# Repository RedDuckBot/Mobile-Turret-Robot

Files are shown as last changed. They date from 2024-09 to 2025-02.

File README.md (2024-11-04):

# Mobile Turret Robot
A differential drive robot, named Stroam, is equipped with a one degree of freedom turret that shoots foam balls. 
Currently, Stroam is only controlled manually where an Xbox 360 controller is used to drive and operate the turret.
Most of Stroam's software was built on the framework ROS2 Humble. Here's the link for a full video of manually operating Stroam: https://www.youtube.com/watch?v=MlZp5pD2vLs

<p align='center'>
    
</p>
<p align='center'>
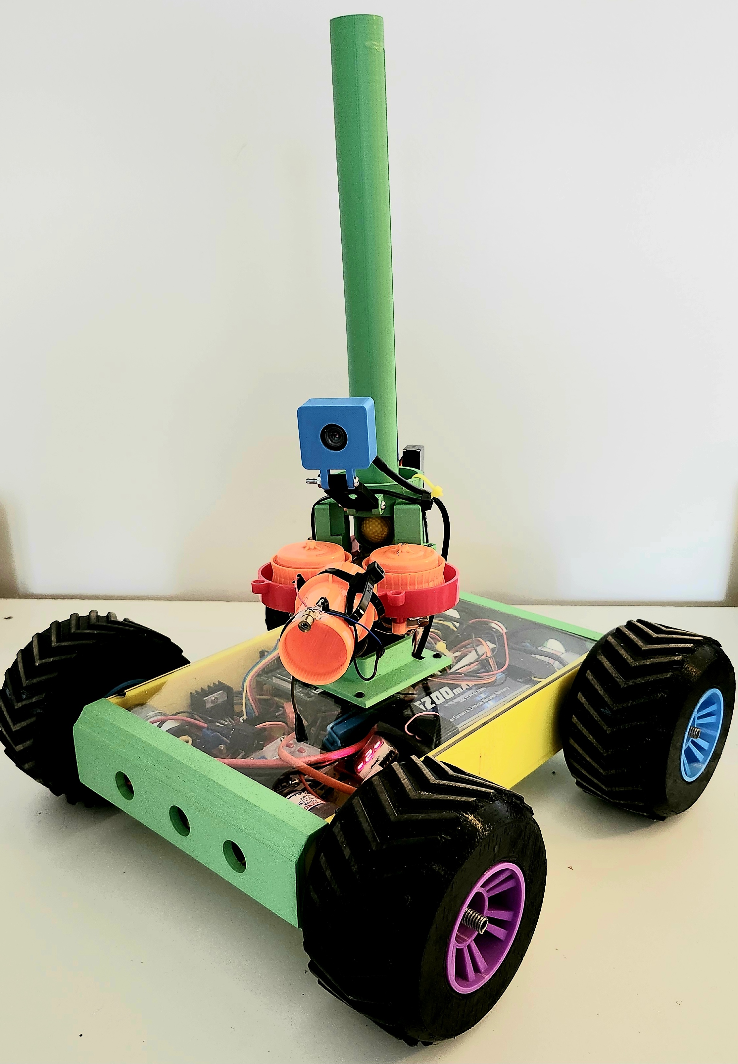
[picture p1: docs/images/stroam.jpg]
    
</p>

## 🗃️ Package Overview
- [`stroam_bringup`](./bot_setup/startup/ros2_ws/src/stroam_bringup/) : Launches camera, robot manager, motor controller, and turret nodes.
- [`stroam_camera`](./bot_setup/startup/ros2_ws/src/stroam_camera/) : Lifecycle node that provides a turret view
- [`stroam_interfaces`](./bot_setup/startup/ros2_ws/src/stroam_interfaces) : Contains action definitions for motor controller and turret operations, as well as 
a message representing Xbox 360 controller inputs.
- [`stroam_manager`](./bot_setup/startup/ros2_ws/src/stroam_manager/) : The main node running on Stroam that routes and translates controller inputs into actions that are used by the motor controller and turret nodes.
- [`stroam_motor_controller`](./bot_setup/startup/ros2_ws/src/stroam_motor_controller/) : Contains an action server for operating Stroam's motors.
- [`stroam_turret`](./bot_setup/startup/ros2_ws/src/stroam_turret/) : Contains an action server for operating Stroam's one degree of freedom turret.
- [`remote_controller`](./remote_setup/ros2_ws/src/remote_controller/) : Contains a publishing node for Xbox 360 controller from a remote computer. 
## 🧰 Hardware

<table>
  <tr>
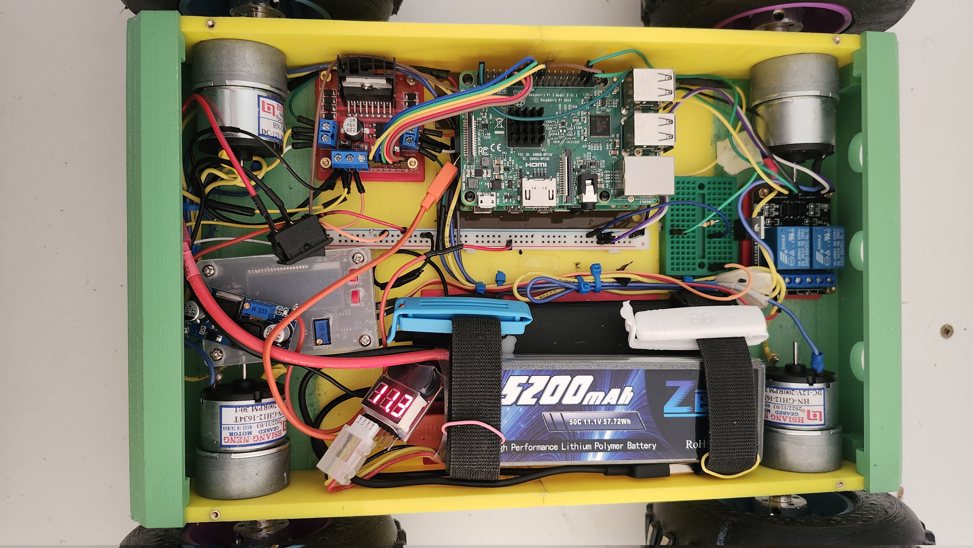
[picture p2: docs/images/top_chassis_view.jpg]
    <td></td>
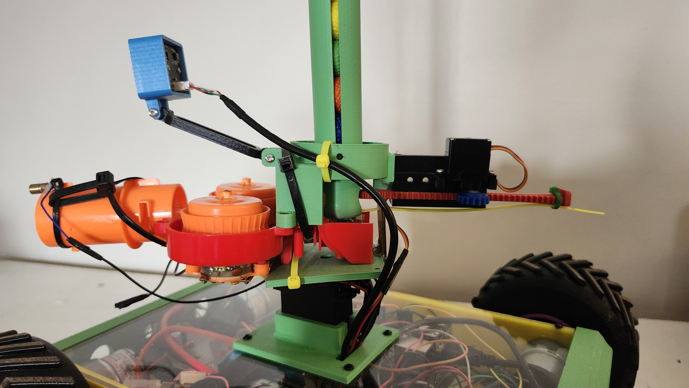
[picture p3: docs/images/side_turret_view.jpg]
    <td></td>
  </tr>
  <tr>
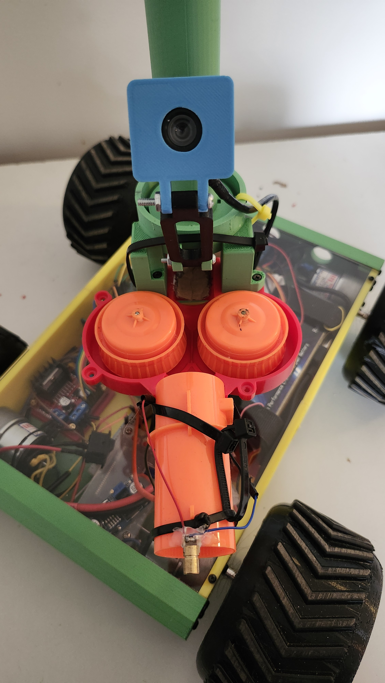
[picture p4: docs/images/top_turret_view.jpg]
    <td></td>
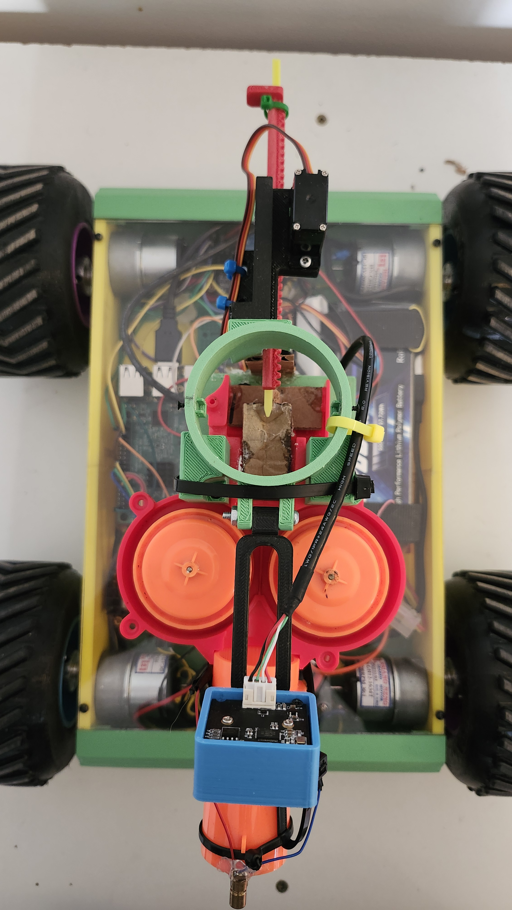
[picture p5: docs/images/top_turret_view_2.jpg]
    <td></td>
  </tr>
</table>

| | Components |
| --| --|
|1| Raspberry PI 3B+ | 
|2| 2 Channel Relay Module | 
|3| Motor Controller L298N |
|4| 2 X DC-DC Step Down Converter |
|5| [4 X DC-12V-200RPM Motors](https://ca.robotshop.com/products/lynxmotion-12vdc-200rpm-078kg-cm-ghm-16-w-rear-shaft?variant=42411388829847) | 
|7| NPN MOSFET |
|8| 460Ω Resistor |
|9| 5V Laser Diode |
|10| USB Camera |
|11| Servo MG996R |
|12| Servo (micro) MG90 |
|13| 12V, 5200mAh LIPO Battery |
|14| 5V, 10000mAh Battery Bank |

### 3D Printed Parts

The only stl files provided in this project are the ones used to build the chassis, given that the turret was a hacked design: turret is composed of 3D printed parts that are fitted to a shooting mechanism taken out a NERF Rival gun. The tires and rims are connected to motors shafts using [6mm universal hubs](https://ca.robotshop.com/products/lynxmotion-hub-02-universal-hub?variant=42413375488151) and 3D printed axel. However, the 3D printed axel was not used in this robot since they kept breaking due to radial load; instead some big bolts were machine down on a metal lath and fitted into the tires. And for the top chassis cover, a clear acyrlic sheet was cut out and fitted using a CNC machine (the stl file for this is found in the 3D_prints directory).

##  ⚡ Circuit Diagrams
The Raspberry PI 3B+ was powered using a 5V power bank while all other devices in the project were powered from the 12V LIPO battery.

### Turret Schematic 
<p align="center">
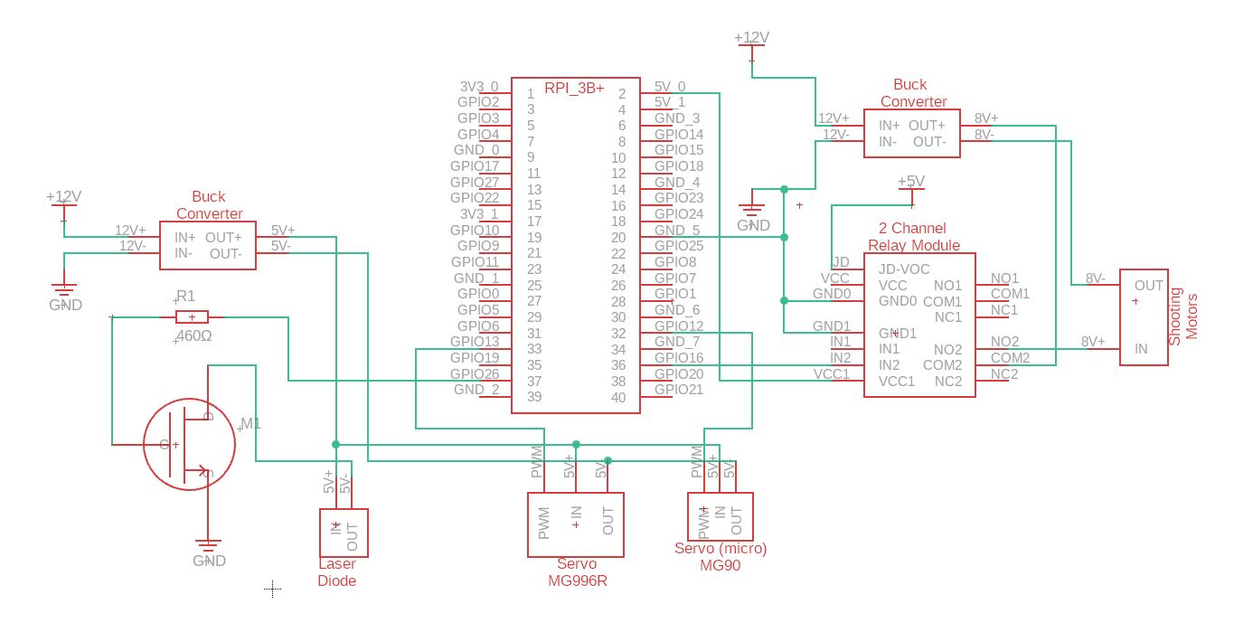
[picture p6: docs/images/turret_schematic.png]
Turret Circuit
  
</p>
Two step down converts were used to power devices for the turret system: 12V to 5V for devices like servos, laser diode and 2 channel relay module, and 12V to 8V for powering the shooting motors. As shown in the turret schematic, a NPN mosfet was used to turn on and off the laser diode by connecting a GPIO pin from the Raspberry PI to it's gate. 

### Drive System Schematic
<p align="center">
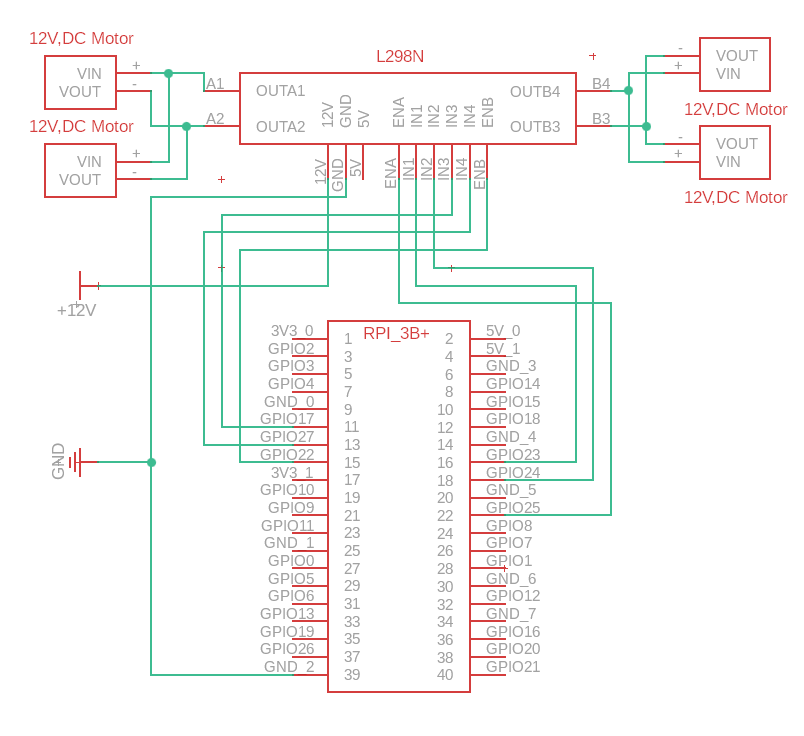
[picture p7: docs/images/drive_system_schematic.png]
Drive system Circuit
  
</p>

As shown in the above schematic, a L298N motor controller is connected to a Rasberry PI 3B+ for operating the 4 DC motors.

## 🔮 Future Work
Currently, Stroam can only be operated manually; however, the plan is to provide the robot with the task of following a route with targets off to the side.
This task is meant to be performed autonmously and will be a computer vision application. Also, there are plans for adding another degree of rotational movement since Stroam only has yaw and no pitch.

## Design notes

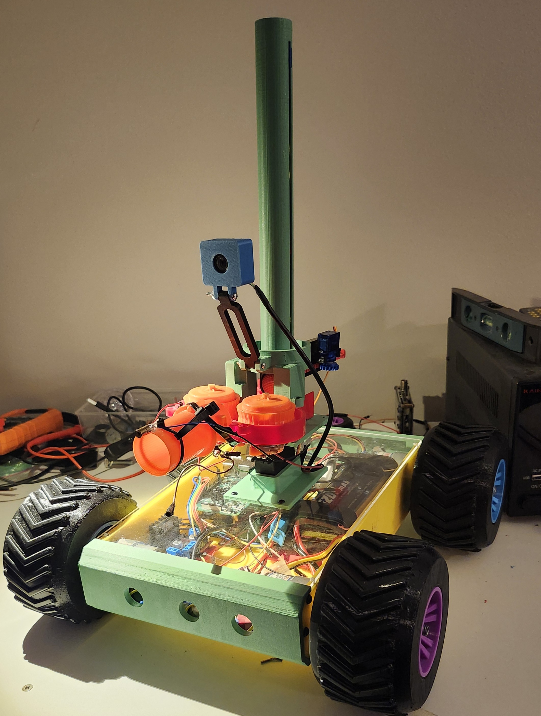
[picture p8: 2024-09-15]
docs/images/bot_pic.jpg

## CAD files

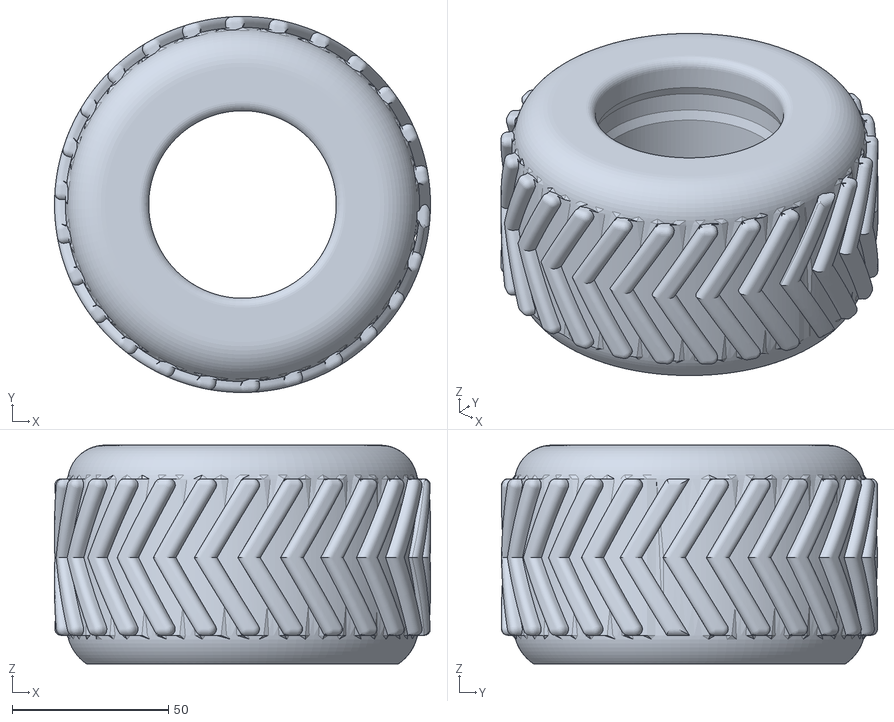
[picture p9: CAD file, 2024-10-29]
3d_prints/tire.stl
120.3 x 120.3 x 70.0

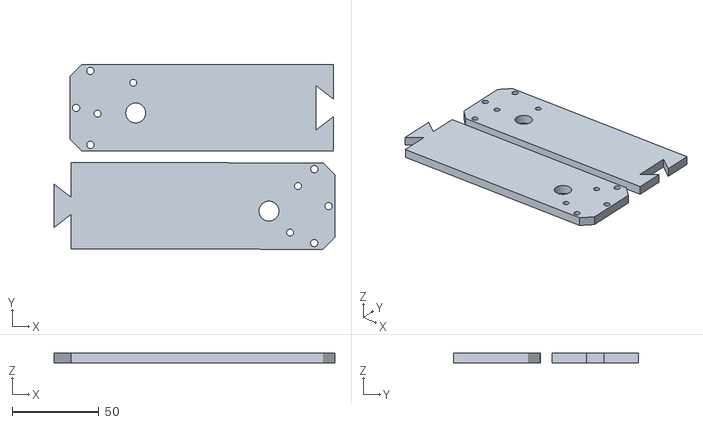
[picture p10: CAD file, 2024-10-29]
3d_prints/chassis_side_cover.stl
161.9 x 106.4 x 5.84

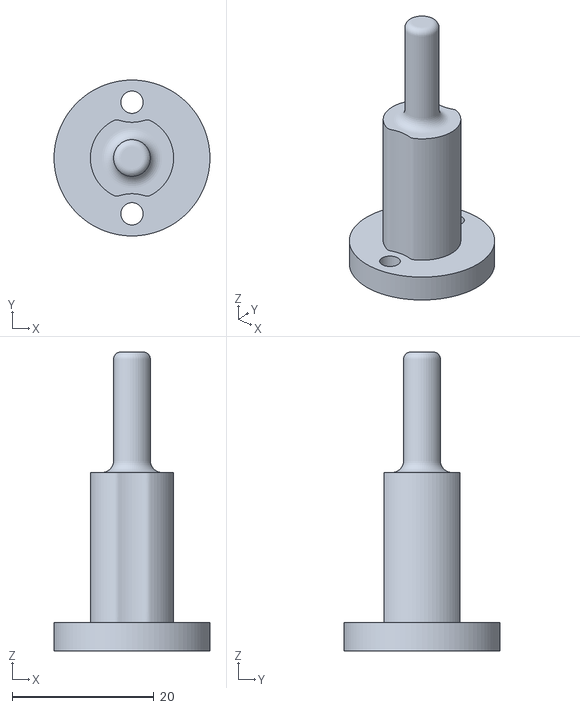
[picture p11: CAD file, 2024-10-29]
3d_prints/axel.stl
22.0 x 22.0 x 42.2

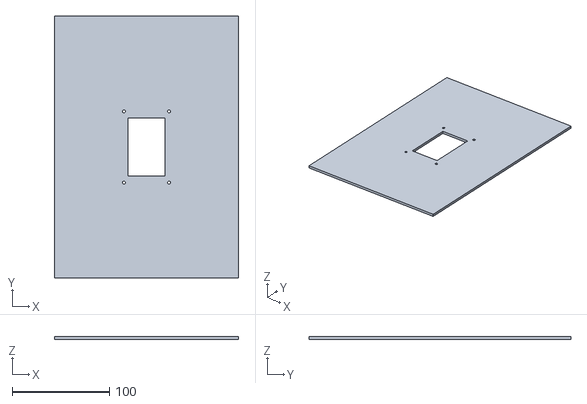
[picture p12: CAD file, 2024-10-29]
3d_prints/chassis_top_cover.stl
190.0 x 270.0 x 3.00

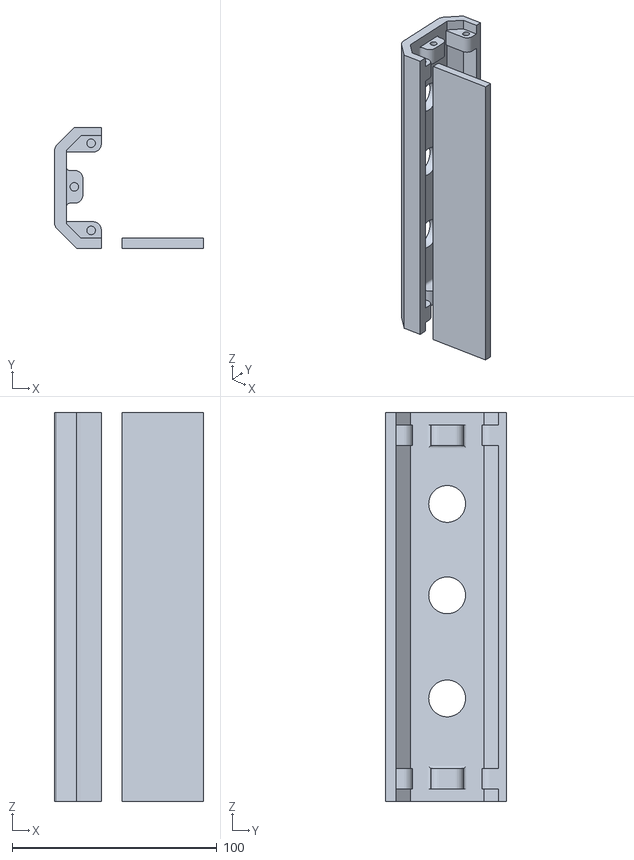
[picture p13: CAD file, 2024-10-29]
3d_prints/chassis_front_back_cover.stl
73.0 x 59.1 x 190.0

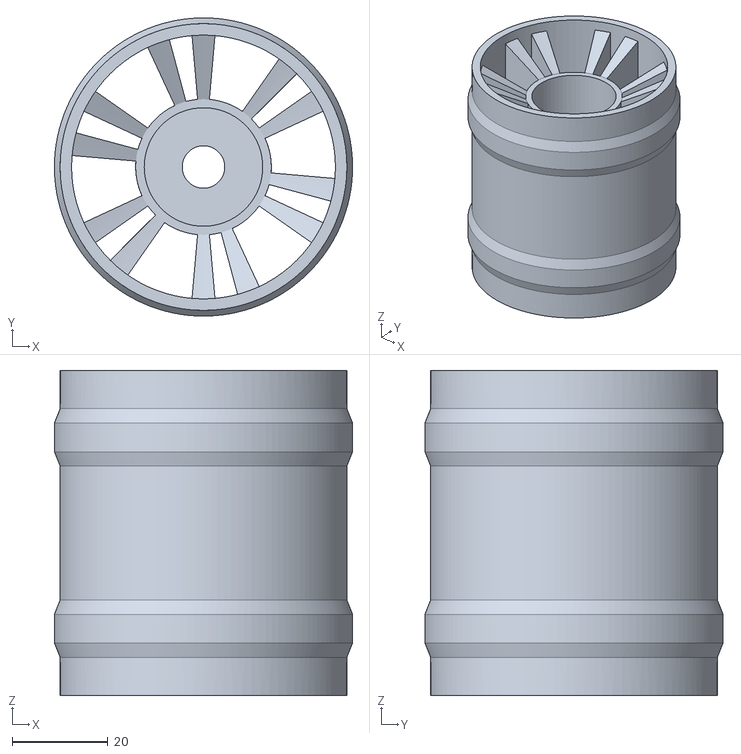
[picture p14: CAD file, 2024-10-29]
3d_prints/rim.stl
62.4 x 62.4 x 68.0

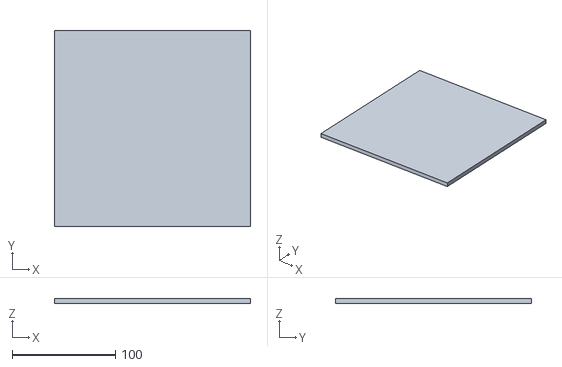
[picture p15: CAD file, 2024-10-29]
3d_prints/chassis_bottom.stl
190.0 x 190.0 x 5.00

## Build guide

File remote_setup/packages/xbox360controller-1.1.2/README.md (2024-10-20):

# xbox360controller
> A pythonic Xbox360 controller API built on top of the `xpad` Linux kernel driver.

[][pypi-url] [][travis-url] [Code Health][landscape-url]

This Python Package aims to provide a pythonic and complete API for your Xbox360 and similar game controllers.
Currently it's built on top of the Linux kernel driver `xpad` so you can use it on almost any Linux distribution including your Rasperry Pi projects etc.

The following features are supported:

- Registering callbacks for **all** Buttons, Axes, Triggers and Hat in a `gpiozero`-inspired way
- Setting the LED circle; all `xpad` provided options are possible: blinking, rotating, setting individual LEDs on and off, ...
- Rumbling, both the left and right side can be controlled from 0 to 100 percent

## Installation

You will need Python 3.4 or above.

Any Linux distribution:

```
pip3 install -U xbox360controller
```

You might also use a _virtual environment_ or do a per-user install by providing the `--user` flag to above command.
Global installations might require the usage of `sudo` or working directly from a root shell but are **not recommended**.

If the `pip3` command cannot be found, try `pip` or make sure to have pip installed properly:

```
sudo apt install python3-pip
```

Of course you don't need `sudo` when working from a root shell.

## Usage

### Basics

```python
import signal
from xbox360controller import Xbox360Controller

def on_button_pressed(button):
    print('Button {0} was pressed'.format(button.name))

def on_button_released(button):
    print('Button {0} was released'.format(button.name))

def on_axis_moved(axis):
    print('Axis {0} moved to {1} {2}'.format(axis.name, axis.x, axis.y))

try:
    with Xbox360Controller(0, axis_threshold=0.2) as controller:
        # Button A events
        controller.button_a.when_pressed = on_button_pressed
        controller.button_a.when_released = on_button_released

        # Left and right axis move event
        controller.axis_l.when_moved = on_axis_moved
        controller.axis_r.when_moved = on_axis_moved

        signal.pause()
except KeyboardInterrupt:
    pass
```

The above code will run until `Ctrl+C` is pressed. Each time on of the left or right axis is moved, the event will be processed. Additionally, the events of the A button are being processed.

See the [API reference](https://github.com/linusg/xbox360controller/blob/master/docs/API.md#xbox360controller-parameters) for a more detailed explanation of the `Xbox360Controller` class and how to use all available buttons, axes and the hat.

### Rumbling

```python
import time
from xbox360controller import Xbox360Controller

with Xbox360Controller() as controller:
    controller.set_rumble(0.5, 0.5, 1000)
    time.sleep(1)
```

This will enable rumble on both sides of the controller with each 50% strength for one second (1000ms). Note that the method call is non-blocking, thus we need to manually wait one second for the rumble to finish. You won't need this in a regular use case with `signal.pause()`.

### LED

```python
import time
from xbox360controller import Xbox360Controller

with Xbox360Controller() as controller:
    controller.set_led(Xbox360Controller.LED_ROTATE)
    time.sleep(1)
    controller.set_led(Xbox360Controller.LED_OFF)
```

This will let the LED circle rotate for one second and then turn it off.

See the [API reference](https://github.com/linusg/xbox360controller/blob/master/docs/API.md#led) for all available LED modes.

### Debug information

```python
from xbox360controller import Xbox360Controller

with Xbox360Controller() as controller:
    controller.info()
```

## Development/contributing

This project is now in a somewhat stable state, and I really appreciate all kinds of contributions - may it be new or improved code, documentation or just a simple typo fix.
Just provide me a PR and I'll be happy to include your work!

For feature requests, general questions or problems you face regarding this package please [open an issue](https://github.com/linusg/xbox360controller/issues/new).

## Release History

Please see [`CHANGES.md`](https://github.com/linusg/xbox360controller/blob/master/CHANGES.md) for a complete release history.

## Authors

- Linus Groh ([**@linusg**](https://github.com/linusg/)) – mail@linusgroh.de

## License

All the code and documentation are distributed under the MIT license. See [`LICENSE`](https://github.com/linusg/xbox360controller/blob/master/LICENSE) for more information.

[pypi-image]: https://img.shields.io/pypi/v/xbox360controller.svg?style=flat-square
[pypi-url]: https://pypi.org/project/xbox360controller/
[travis-image]: https://img.shields.io/travis/linusg/xbox360controller/master.svg?style=flat-square
[travis-url]: https://travis-ci.org/linusg/xbox360controller
[landscape-image]: https://landscape.io/github/linusg/xbox360controller/master/landscape.svg?style=flat-square
[landscape-url]: https://landscape.io/github/linusg/xbox360controller

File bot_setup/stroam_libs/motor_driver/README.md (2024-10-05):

# Motor Driver

C++ library for representing a motor controller. Stroam is using an L298N motor controller. The export target file in ./build/cmake, after build sys. & compilation, is called MotorDriverTargets.cmake .

## Dependencies
- [`fmt`](https://github.com/fmtlib/fmt) : C++ library for formatting
- [`device`](../device/) : C++ library from Stroam's libraries 
- [`turret`](../turret/) : C++ library from Stroam's libraries; MotorDriver uses DigitalOutputDevice from this lib 

## Pinouts
 |GPIO Pin| L298N Pin | Motors | 
| --| --| --|
|23| IN1 | Right side | 
|24| IN2 | Right side |
|25| ENA | Right side |
|17| IN3 | Left side |
|27| IN4 | Left side |
|22| ENB | Left side |

Table above represents the default pinouts.

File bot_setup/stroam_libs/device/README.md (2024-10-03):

# Device

C++ library containing a parent class called 'Device' for any C++ class in Stroam's 
library that utilzes the C library pigpio. This class handles initialization for
pigpiod daemon and closing it after all devices have been closed.

## Dependencies
- [pigpio_if2](https://github.com/joan2937/pigpio) C library for GPIO control

## Stroam's Device Classes
- DigitalOutputDevice --> turret library
- Servo --> turret library

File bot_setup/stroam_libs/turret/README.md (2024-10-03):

# Turret 

A C++ library representing an interface for Stroam's turret. 

## Dependencies
- [`pigpio_if2`](https://github.com/joan2937/pigpio) : C library for GPIO control using pigpiod daemon
- [`fmt`](https://github.com/fmtlib/fmt) : C++ library for formatting
- [`device`](../device/) : C++ library from Stroam's libraries; contains a 
parent class, called Device, that handles initialization and deconstruction for devices found in this library

## Pinouts
|Device| GPIO Pin |
| --| --|
|Laser| 26 |
|Base Servo| 13 |
|Pusher Rod Servo| 12 |
|Shooting Motors| 16 |

Table above represents the default pinouts.

## Before Build sys. & Compilation 
To handle the 'device' dependency create a symbolic link to the export target file found in Stroam's device library. Name this file as 'DeviceTargets.cmake'.
Note: this file is found in the cmake directory of build in device library after compiling it.

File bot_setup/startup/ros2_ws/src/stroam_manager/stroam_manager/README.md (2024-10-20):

## Stroam Manager Package
ROS2 package contains a manager node for routing controller inputs.
Turret button presses are sent to turret_button, turret joy-stick moves sent
to turret_joy, and motors joy-stick moves to motor_controller nodes.

# Dependencies
- [`stroam_interfaces`] (../stroam_interfaces) : Contains definitions for Stroam's instructions (actions) and Xbox controller inputs (message)
- [`turret`] (../../../)

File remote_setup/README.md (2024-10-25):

# Remote Setup
Before operating Stroam manually update the cyclonedds.xml file with both Stroams and the remote computer IP addresses.
Run the script 'remote_manual_control.bash' from ./startup to begin manual operation.

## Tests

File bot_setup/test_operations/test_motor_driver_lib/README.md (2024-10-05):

# Test Motor Driver Library

This project consumes the target MotorDriver::motorDriver from Stroam's motor driver library and checks for the working operations of the motor driver. 

##Dependencies
- fmt
- pigpio_if2
- Stroam's motor driver library
- Stroam's device library
- Stroam's turret library (MotorDriver uses DigitalOutputDevices from turret lib)

## Before Build sys. & Compilation
In the root directory of this test project, create two symbolic links:
- DeviceTargets.cmake (from device library)
- MotorDriverTargets.cmake (from motor driver library)

Note: both export target files are found in the libraries build/cmake directory after building & compiling them

## Before running Test

Start pigpiod daemon:

```
sudo pigpiod
sudo killall pigpiod #After done running test close pigpiod daemon
```

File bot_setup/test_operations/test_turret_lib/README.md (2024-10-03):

# Test Turret Library

This test project consumes the target Turret::turret from Stroam's turret library,
and checks for the working operations of turret interface.

## Dependencies 
- fmt
- pigpio_if2
- Stroam's turret library 
- Stroam's device library

## Before Build & Compilation
In the root directory, Create symbolic links for both Stroam's libraries device and turret: 
- TurretTargets.cmake
- DeviceTargets.cmake

Note: both export target files are found in the libraries build/cmake directory after they are built

## Before running Test
Start pigpiod daemon:
```
sudo pigpiod
sudo killall pigpiod #After done running test close pigpiod daemon
```

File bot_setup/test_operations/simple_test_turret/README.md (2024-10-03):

Basic test only utilizes pigpio library for testing Stroams 1 degree of freedom turret. Run the executable ./testTurret in build directory. Moreover, this test
is simple since it makes use of gpioInitialize() for direct hardware control, meaning
only one program can have control over the GPIO hardware, so no connection is made
to pigpiod daemon.

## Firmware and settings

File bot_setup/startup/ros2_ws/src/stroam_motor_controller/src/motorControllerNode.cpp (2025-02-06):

#include "rclcpp/rclcpp.hpp"
#include "rclcpp_action/rclcpp_action.hpp"
#include "stroam_interfaces/action/motors_instruct.hpp"
#include "motor_driver/motorDriver.hpp"

//L289N pins to GPIO pins
#define IN1 23
#define IN2 24
#define IN3 17
#define IN4 27
#define ENA 25
#define ENB 22

using motorDriver:: MotorDriver;
using motorDriver::MotorDirection;
using MotorsInstruct = stroam_interfaces::action::MotorsInstruct;
using MotorsGoalHandle = rclcpp_action::ServerGoalHandle<MotorsInstruct>;
using namespace std::placeholders;

/**
 * @class MotorNode
 * @brief Represents an action server for Stroam's motor controller (L298N). 
 * 
 * This class node communicates with Stroam's manager node to enable movement of 
 * entire robot.
 */
class MotorControllerNode : public rclcpp::Node 
{
    public:
        MotorControllerNode() :
	    Node("Motors_Node"),
            leftMotors_(std::make_unique<MotorDriver>(
				IN3, IN4, ENB, "leftMotors")),
            rightMotors_(std::make_unique<MotorDriver>(
				IN1, IN2, ENA, "rightMotors"))
        {
		motor_control_enabled_ = false;
		callback_group_1_ = this->create_callback_group(
            		rclcpp::CallbackGroupType::Reentrant);

		motor_contr_server_ = rclcpp_action::create_server<MotorsInstruct>(
				this,
				"motor_controller_actions",
				std::bind(&MotorControllerNode::goal_callback, this, _1, _2),
				std::bind(&MotorControllerNode::cancel_callback, this, _1),
				std::bind(&MotorControllerNode::handle_accepted_callback, this, 
					_1),
				rcl_action_server_get_default_options(),
				callback_group_1_
		);
		
		RCLCPP_INFO(this->get_logger(), "Motor controller node initialized");
        }

    private:
    	std::unique_ptr <MotorDriver> leftMotors_; 
    	std::unique_ptr <MotorDriver> rightMotors_; 

	bool motor_control_enabled_;
	std::mutex mutex_;

	std::shared_ptr<MotorsGoalHandle> current_handle_goal_;//motor instructs
	rclcpp_action::Server<MotorsInstruct>::SharedPtr motor_contr_server_;
	rclcpp::CallbackGroup::SharedPtr callback_group_1_;
	
	/**
	 * @brief Handle incoming motor controller goal inside MotorsInstruct
	 *
	 * A new motor instruction (goal) is accepted provided that a current
	 * goal isn't being executed, otherwise reject new goal.
	 */
	rclcpp_action::GoalResponse goal_callback(
		const rclcpp_action::GoalUUID &uuid, 
		std::shared_ptr<const MotorsInstruct::Goal> new_motors_goal)
	{
		{
			std::lock_guard<std::mutex> lock(mutex_);
			if (current_handle_goal_) 
			{
				if (current_handle_goal_ -> is_active())
				{
					RCLCPP_INFO(this->get_logger(), 
						"[Motor Server]: A goal is active, rejected new goal");
					return rclcpp_action::GoalResponse::REJECT;
				}
			}
		}

		(void) uuid;
		(void) new_motors_goal;
		return rclcpp_action::GoalResponse::ACCEPT_AND_EXECUTE;
	}

	/**
	 * @brief Handle a rejected motor controller goal request
	 * 
	 */
	rclcpp_action::CancelResponse cancel_callback(
		const std::shared_ptr<MotorsGoalHandle> goal_handle)
	{
		(void) goal_handle;
		return rclcpp_action::CancelResponse::ACCEPT;
	}
	
	/**
	 * @brief Handle accepted motor goal sent from Stroam manager node
	 *@param new_goal_handle the latest accepted motor instructions
	 */
	void handle_accepted_callback(
		const std::shared_ptr<MotorsGoalHandle> new_goal_handle)
	{
		{
			std::lock_guard<std::mutex> lock(mutex_);
			this -> current_handle_goal_ = new_goal_handle;
		}

		execute_motor_goal_(new_goal_handle);
		send_goal_result_(new_goal_handle);

	}

	/**
	 *@brief Set left and right motor efforts and directions
	 * 
	 * @param goal_handle the action containing motor joy-stick values
	 */
	void execute_motor_goal_(const std::shared_ptr<MotorsGoalHandle> 
		goal_handle)
	{

		double new_left_motors_effort, new_right_motors_effort;

		auto goal = goal_handle -> get_goal();
		float left_joy_y = goal -> left_joy_stick_y;
		float right_joy_y = goal -> right_joy_stick_y; 
		
		MotorDirection left_joy_dir = MotorDirection::Forward;
		MotorDirection right_joy_dir = MotorDirection::Forward;
		
		//Set left joy stick direction
		if (left_joy_y < 0)
		{
			left_joy_dir = MotorDirection::Forward;
		} 
		else 
		{
			left_joy_dir = MotorDirection::Backward;
		}

		//Set right joy stick direction
		if (right_joy_y < 0)
		{
			right_joy_dir = MotorDirection::Forward;
		}
		else
		{
			right_joy_dir = MotorDirection::Backward;
		}

		//Check for change in motor directions and set them
		if (leftMotors_->getDirection() != left_joy_dir)
		{
			leftMotors_->setDirection(left_joy_dir);
		}
		if (rightMotors_->getDirection() != right_joy_dir)
		{
			rightMotors_->setDirection(right_joy_dir);
		}

		new_left_motors_effort = controllerInput_to_motorEffort(
			abs(left_joy_y));
		new_right_motors_effort = controllerInput_to_motorEffort(
			abs(right_joy_y));

		leftMotors_->setEffortPercent(new_left_motors_effort);
		rightMotors_->setEffortPercent(new_right_motors_effort);
	}

	/**
	 *@brief Take a joy-stick value and convert it to a percentage [0,1]
	 *@return the percentage or effort
	 */
	double controllerInput_to_motorEffort(double joy_stick_input) 
	{
		return joy_stick_input * 100;
	}

	/**
	 *@brief Send back the result of accepted and executed motor goal
	 */
	void send_goal_result_(const std::shared_ptr<MotorsGoalHandle> goal_handle)
	{
		auto result = std::make_shared<MotorsInstruct::Result>();
		result->result = "Success";
		goal_handle->succeed(result);
	}
};


int main(int argc, char **argv)
{
    rclcpp::init(argc, argv);

    auto motor_controller_node = std::make_shared<MotorControllerNode>();
    rclcpp::executors::MultiThreadedExecutor executor;

    executor.add_node(motor_controller_node);
    executor.spin();

    rclcpp::spin(motor_controller_node->get_node_base_interface());
    rclcpp::shutdown();

    return 0;
}

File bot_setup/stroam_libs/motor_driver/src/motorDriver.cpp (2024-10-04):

#include "../include/motor_driver/motorDriver.hpp"

namespace motorDriver
{
    MotorDriver::MotorDriver(
        unsigned int input_1_pin, unsigned int input_2_pin,
        unsigned int enable_PWM_pin, std::string motorName):
            Device(enable_PWM_pin, motorName + "_enablePin"),
            input_1_pin_(input_1_pin, motorName + "_inputPin1"),
            input_2_pin_(input_2_pin, motorName + "_inputPin2"),
            motor_effort_percent_(0.0)
    {
        this -> enablePin_ = enable_PWM_pin;
        setDirection(motorDriver::MotorDirection::Forward);
    }

    MotorDriver::~MotorDriver()
    {
        setEffortPercent(0.0);
    }

    MotorDirection MotorDriver::getDirection() const
    {
        return motor_direction_;
    }

    void MotorDriver::setDirection(MotorDirection direction)
    {
        motor_direction_ = direction;
        if (direction == MotorDirection::Forward) 
        {
            input_1_pin_.on();
            input_2_pin_.off();
        }
        else
        {
            input_1_pin_.off();
            input_2_pin_.on();
        }
    }

    double MotorDriver::getEffortPercent() const
    {
        return motor_effort_percent_;
    }

    void MotorDriver::setEffortPercent(double new_percent)
    {

        if ((new_percent < 0.0) || (new_percent > 100.0))
        {
            throw std::runtime_error(
                fmt::format("Effort value {} is invalid. Valid range [0.0, 100.0]", 
                new_percent)); 
        }

        motor_effort_percent_ = new_percent / 100.0;

        auto int_percent = static_cast<uint8_t>(255.0 * motor_effort_percent_);
        auto result = set_PWM_dutycycle(getGPIOHandle(), enablePin_, int_percent);
        if (result == 0)
        {
            return;
        }

        switch (result)
        {       
            case PI_BAD_USER_GPIO:
            {
            throw std::runtime_error(fmt::format("{} is a bad GPIO pin", enablePin_));
            }

            case PI_BAD_DUTYCYCLE:
            {
                throw std::runtime_error(
                    fmt::format("Bad duty cycle specified for gpio pin {}", enablePin_));
            }

            default:
            {
                throw std::runtime_error(
                    fmt::format("Unexpected error encountered when setting mode specified for gpio pin {} (Error = {})", 
                        enablePin_, result));
            }
    }
    }
}

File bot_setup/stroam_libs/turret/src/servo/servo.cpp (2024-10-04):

#include "servo.hpp"

namespace stroams_servo
{
    Servo::Servo(unsigned int servoPin, unsigned int min_pulse_width, 
        unsigned int max_pulse_width, int starting_angle, 
        const std::string& servoName): 
            Device(servoPin, servoName) 
    {
        this -> starting_angle_ = starting_angle;
        this -> servoPin_ = servoPin;
        this -> min_pulse_width_ = min_pulse_width;
        this -> max_pulse_width_ = max_pulse_width;

        set_PWM_frequency(getGPIOHandle(), servoPin_,50); //50 Hz

        rotate_to_pos(starting_angle);
    }

    Servo::~Servo()
    {
        rotate_to_pos(starting_angle_);
        sleep(2);
        rotate_to_pos(-1,true);
    }

    void Servo::rotate_to_pos(int angle, bool stop_servo)
    {
        unsigned pwm_value;

        if (stop_servo)
        {
            pwm_value = 0;
        }
        else
        {
            pwm_value = get_pwm_value_from_angle(angle);
        }

        set_servo_pulsewidth(getGPIOHandle(), servoPin_, pwm_value);
    }

    unsigned int Servo::get_pwm_value_from_angle(int angle)
    {
        //Pulse widths are in microseconds
        double x;
        int pwm_value;
        double pwm_range = max_pulse_width_ - min_pulse_width_;

        x = angle / 180.0;
        x = pwm_range * x;
        pwm_value = (int) (min_pulse_width_ + x);

        if (pwm_value > max_pulse_width_)
        {
            pwm_value = max_pulse_width_;
        }

        if (pwm_value < min_pulse_width_)
        {
            pwm_value = min_pulse_width_;
        }

        return pwm_value;
    }
}

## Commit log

2024-09-15 Added LaserPointer class
2024-09-17 Finalized test code for 1DOF turret by adding pusher rod
2024-09-23 Implemented laserPointer class in turret library
2024-09-24 Implemented laser and servo components in turret library
2024-10-02 Added a new Stroam lib called device
2024-10-03 Finished implementing Stroam's device lib and update both test turret project and turret lib
2024-10-03 Updated Stroam's device library to be able to connect with pigpiod daemon and made changes to match this in turret lib
2024-10-04 Updated device and turret libs
2024-10-04 Finished implementing Stroam's motor driver library
2024-10-05 Finished testing Stroam's motor driver library
2024-10-06 Added ros2 pkg for Stroam's camera
2024-10-07 Finished implementing remote camera node
2024-10-07 Finished implementing lifecycle node for bot's camera
2024-10-07 Updated remote camera ros2 pkg
2024-10-07 Added stroam's ros2 libs motor_controller,interface, & turret to bot_setup
2024-10-09 Finished testing camera node in bot_setup
2024-10-09 Finished setting up base node files for Stroam's ROS2 pkgs turret and motor controller
2024-10-10 Finished implementing motor controller node
2024-10-24 Added pic for turret schematic
2024-10-24 Added the finalized turret schematic
2024-10-24 Added pic for wiring diagram for drive system
2024-10-29 Added a directory containing stl files for chassis
    [axel.stl, chassis_bottom.stl, chassis_front_back_cover.stl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]
2024-10-29 Remove stl files
    [axel.stl, chassis_bottom.stl, chassis_front_back_cover.stl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]
